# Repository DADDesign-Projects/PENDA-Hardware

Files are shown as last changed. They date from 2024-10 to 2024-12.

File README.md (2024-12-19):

# PENDA: Platform for Effects oN DAisy

Welcome to the PENDA project! This repository contains the schematics and PCB layouts created with KiCad 8.0 for a versatile digital effects platform that utilizes the **Daisy-Seed** board from **ElectroSmith**.

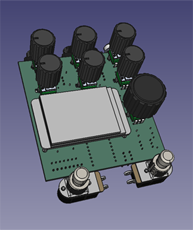
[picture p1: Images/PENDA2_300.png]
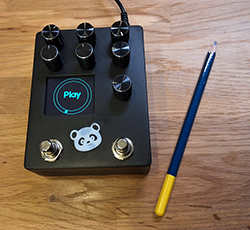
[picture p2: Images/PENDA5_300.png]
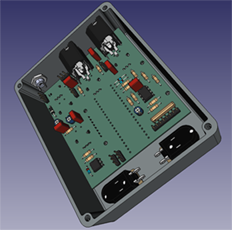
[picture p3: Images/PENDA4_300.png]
  

## Author

DAD Design

## Overview / Features

PENDA is designed to provide a range of audio effects through a user-friendly interface. The platform includes:

- **Mono Input and Output**: Simplified connectivity for easy integration into your audio setup.
- **Momentary Footswitches**: Two footswitches for hands-free operation of effects.
- **2-inch SPI Display**: Featuring the ST7789 from Waveshare, providing a clear and compact user interface (other display options are available).
- **MIDI Input**: Allows for easy integration with MIDI controllers and other devices.
- **Control Options**:
  - **4 Encoders with Pushbutton**: For easy parameter adjustment and selection.
  - **3 Analog Potentiometers**: To control input levels and the Dry/Wet mix.
- **Fully Analog Dry Circuit**: Ensures a high-quality dry signal path, maintaining the integrity of your original sound.

## Content

The **Fab** directory contains all the necessary files for fabrication.
The **PENDA** directory contains the source files for KiCad 8.0.

## Contributing

We welcome contributions to the PENDA project! If you have suggestions or improvements, please open an issue or submit a pull request.

## License

This project is licensed under the MIT License.

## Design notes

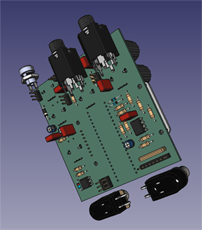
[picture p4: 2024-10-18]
Images/PENDA3_300.png

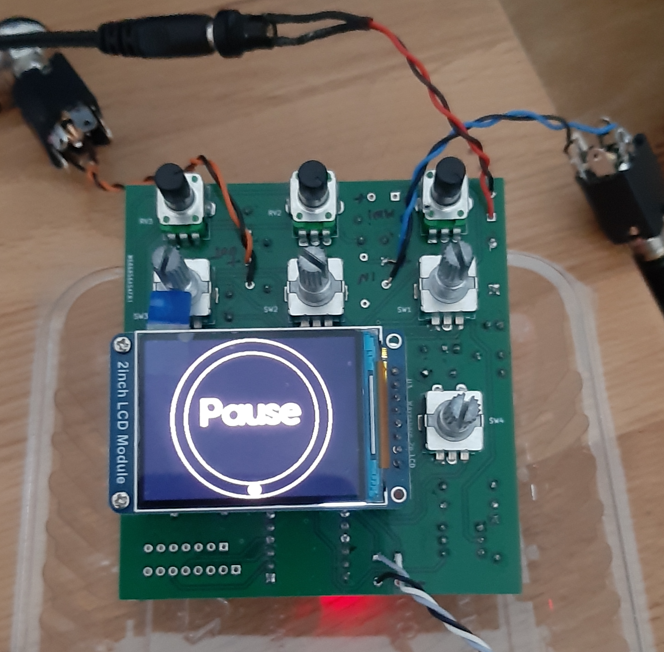
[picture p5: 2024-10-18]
Images/PENDA V1.0.png

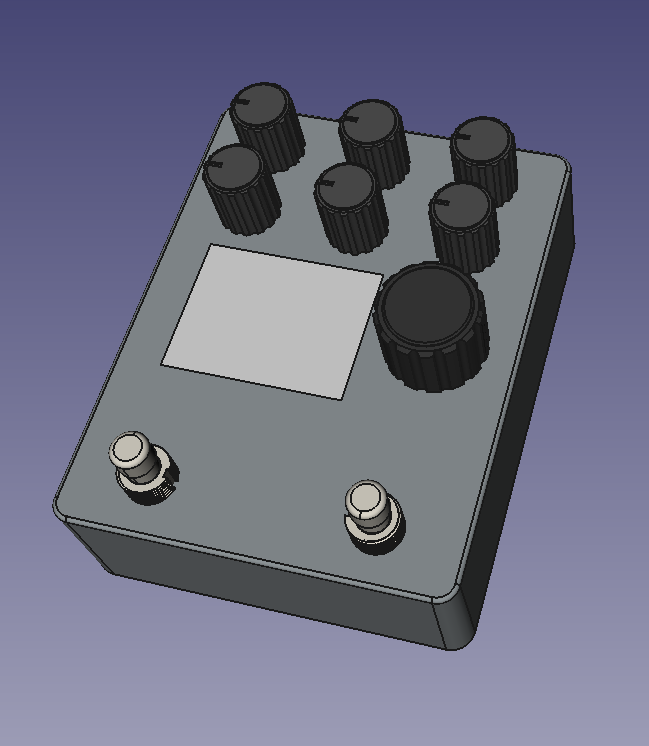
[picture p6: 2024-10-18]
Images/PENDA1.png

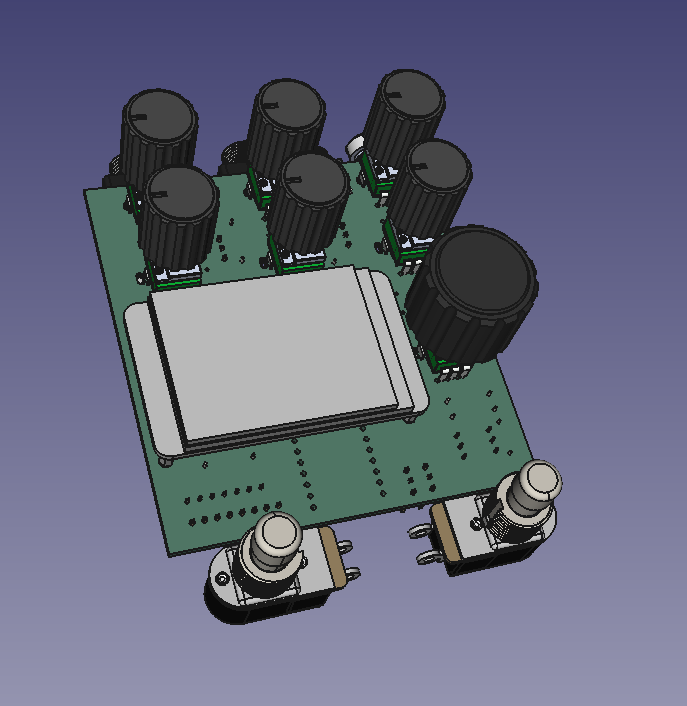
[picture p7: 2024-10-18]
Images/PENDA2.png

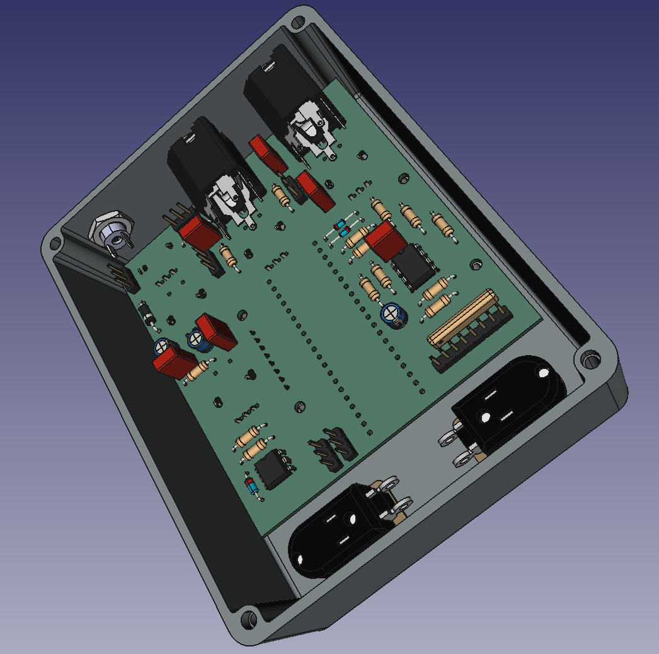
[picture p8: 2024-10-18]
Images/PENDA4.png

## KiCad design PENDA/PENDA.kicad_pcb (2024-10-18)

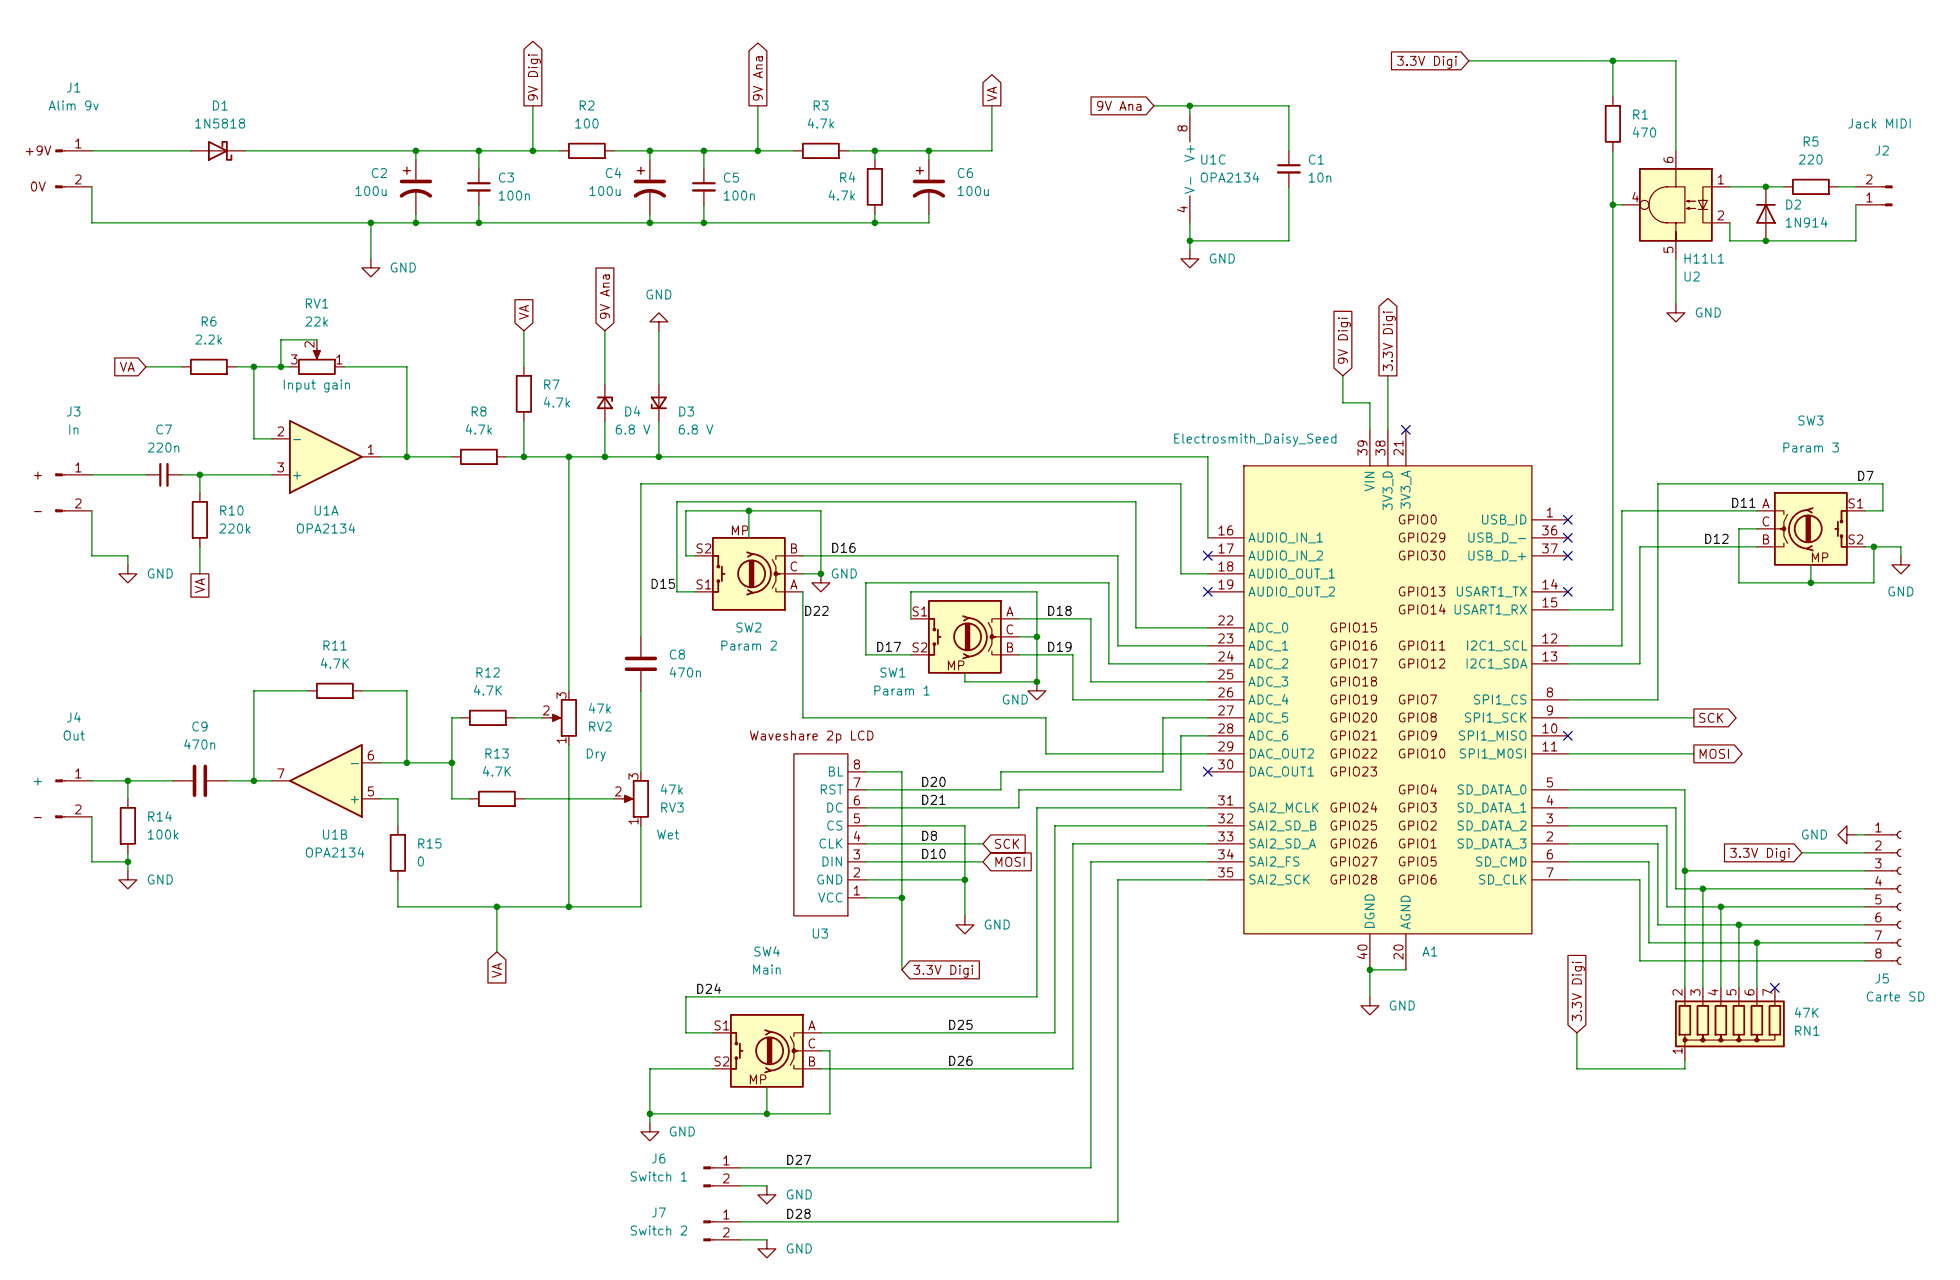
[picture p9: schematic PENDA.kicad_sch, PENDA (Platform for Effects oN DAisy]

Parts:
A1: Electrosmith_Daisy_Seed
C1: 10n; C_Rect_L7.0mm_W3.5mm_P5.00mm
C2, C4, C6: 100u; CP_Radial_D5.0mm_P2.50mm
C3, C5: 100n; C_Rect_L7.0mm_W3.5mm_P5.00mm
C7: 220n; C_Rect_L7.0mm_W3.5mm_P5.00mm
C8, C9: 470n; C_Rect_L7.0mm_W3.5mm_P5.00mm
D1: 1N5818; D_DO-41_SOD81_P10.16mm_Horizontal
D2: 1N914; D_DO-35_SOD27_P7.62mm_Horizontal
D3, D4: 6.8 V; D_DO-34_SOD68_P10.16mm_Horizontal
J1: Alim 9v; PinHeader_1x02_P5.08mm_Vertical
J2: Jack MIDI; PinHeader_1x02_P5.08mm_Vertical
J3: In; PinHeader_1x02_P5.08mm_Vertical
J4: Out; PinHeader_1x02_P5.08mm_Vertical
J5: Carte SD; PinHeader_1x08_P2.54mm_Vertical
J6: Switch 1; PinHeader_1x02_P5.08mm_Vertical
J7: Switch 2; PinHeader_1x02_P5.08mm_Vertical
R1: 470; R_Axial_DIN0207_L6.3mm_D2.5mm_P10.16mm_Horizontal
R2: 100; R_Axial_DIN0207_L6.3mm_D2.5mm_P10.16mm_Horizontal
R3, R4, R7, R8: 4.7k; R_Axial_DIN0207_L6.3mm_D2.5mm_P10.16mm_Horizontal
R5: 220; R_Axial_DIN0207_L6.3mm_D2.5mm_P10.16mm_Horizontal
R6: 2.2k; R_Axial_DIN0207_L6.3mm_D2.5mm_P10.16mm_Horizontal
R10: 220k; R_Axial_DIN0207_L6.3mm_D2.5mm_P10.16mm_Horizontal
R11, R12, R13: 4.7K; R_Axial_DIN0207_L6.3mm_D2.5mm_P10.16mm_Horizontal
R14: 100k; R_Axial_DIN0207_L6.3mm_D2.5mm_P10.16mm_Horizontal
R15: 0; R_Axial_DIN0207_L6.3mm_D2.5mm_P10.16mm_Horizontal
RN1: 47K; R_Array_SIP7
RV1: 22k; Potentiometer_Alpha_RD901F-40-00D_Single_Vertical_Center
RV2, RV3: 47k; Potentiometer_Alpha_RD901F-40-00D_Single_Vertical_Center
SW1: Param 1; RotaryEncoder_Alps_EC11E-Switch_Vertical_H20mm_Center
SW2: Param 2; RotaryEncoder_Alps_EC11E-Switch_Vertical_H20mm_Center
SW3: Param 3; RotaryEncoder_Alps_EC11E-Switch_Vertical_H20mm_Center
SW4: Main; RotaryEncoder_Alps_EC11E-Switch_Vertical_H20mm_Center
U1: OPA2134; DIP-8_W7.62mm
U2: H11L1; DIP-6_W7.62mm
U3: Waveshare 2 p LCD V2

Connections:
3.3V Digi: A1.38 (3V3_D), J5.2, R1.2, RN1.1 (common), U2.6, U3.1 (VCC), U3.8 (BL)
9V Ana: C1.1, C4.1, C5.1, D4.1 (K), R2.2, R3.1, U1.8 (V+)
9V Digi: A1.39 (VIN), C2.1, C3.1, D1.1 (K), R2.1
/D7: A1.8 (SPI1_CS), SW3.S1
/D11: A1.12 (I2C1_SCL), SW3.A
/D12: A1.13 (I2C1_SDA), SW3.B
/D15: A1.22 (ADC_0), SW2.S1
/D16: A1.23 (ADC_1), SW2.B
/D17: A1.24 (ADC_2), SW1.S2
/D18: A1.25 (ADC_3), SW1.A
/D19: A1.26 (ADC_4), SW1.B
/D20: A1.27 (ADC_5), U3.7 (RST)
/D21: A1.28 (ADC_6), U3.6 (DC)
/D22: A1.29 (DAC_OUT2), SW2.A
/D24: A1.31 (SAI2_MCLK), SW4.S1
/D25: A1.32 (SAI2_SD_B), SW4.A
/D26: A1.33 (SAI2_SD_A), SW4.B
/D27: A1.34 (SAI2_FS), J6.1
/D28: A1.35 (SAI2_SCK), J7.1
GND: A1.20 (AGND), A1.40 (DGND), C1.2, C2.2, C3.2, C4.2, C5.2, C6.2, D3.2 (A), J1.2, J3.2 (-), J4.2, J5.1, J6.2, J7.2, R4.1, R14.2, SW1.C, SW1.MP, SW1.S1, SW2.C, SW2.MP, SW2.S2, SW3.C, SW3.MP, SW3.S2, SW4.C, SW4.MP, SW4.S2, U1.4 (V-), U2.5, U3.2 (GND), U3.5 (CS); also elsewhere on the board
MOSI: A1.11 (SPI1_M0SI), U3.3 (DIN)
unnamed: A1.16 (AUDIO_IN_1), D3.1 (K), D4.2 (A), R7.1, R8.2, RV2.3
unnamed: A1.18 (AUDIO_OUT_1), C8.1
unnamed: A1.7 (SD_CLK), J5.8
unnamed: A1.6 (SD_CMD), J5.7, RN1.6 (R5)
unnamed: A1.5 (SD_DATA_0), J5.3, RN1.2 (R1)
unnamed: A1.4 (SD_DATA_1), J5.4, RN1.3 (R2)
unnamed: A1.3 (SD_DATA_2), J5.5, RN1.4 (R3)
unnamed: A1.2 (SD_DATA_3), J5.6, RN1.5 (R4)
unnamed: A1.15 (USART1_RX), R1.1, U2.4
unnamed: C8.2, RV3.3
unnamed: C9.1, R11.1, U1.7
unnamed: D1.2 (A), J1.1
unnamed: D2.2 (A), J2.1, U2.2
unnamed: D2.1 (K), R5.1, U2.1
unnamed: J2.2, R5.2
unnamed 36: C7.1, J3.1 (+); also elsewhere on the board
unnamed: C9.2, J4.1, R14.1
unnamed: R8.1, RV1.1, U1.1
unnamed: R12.2, RV2.2
unnamed: R13.2, RV3.2
unnamed: C7.2, R10.1, U1.3 (+)
unnamed: R6.2, RV1.2, RV1.3, U1.2 (-)
unnamed: R15.2, U1.5 (+)
unnamed: R11.2, R12.1, R13.1, U1.6 (-)
SCK: A1.9 (SPI1_SCK), U3.4 (CLK)
VA: C6.1, R3.2, R4.2, R6.1, R7.2, R10.2, R15.1, RV2.1, RV3.1

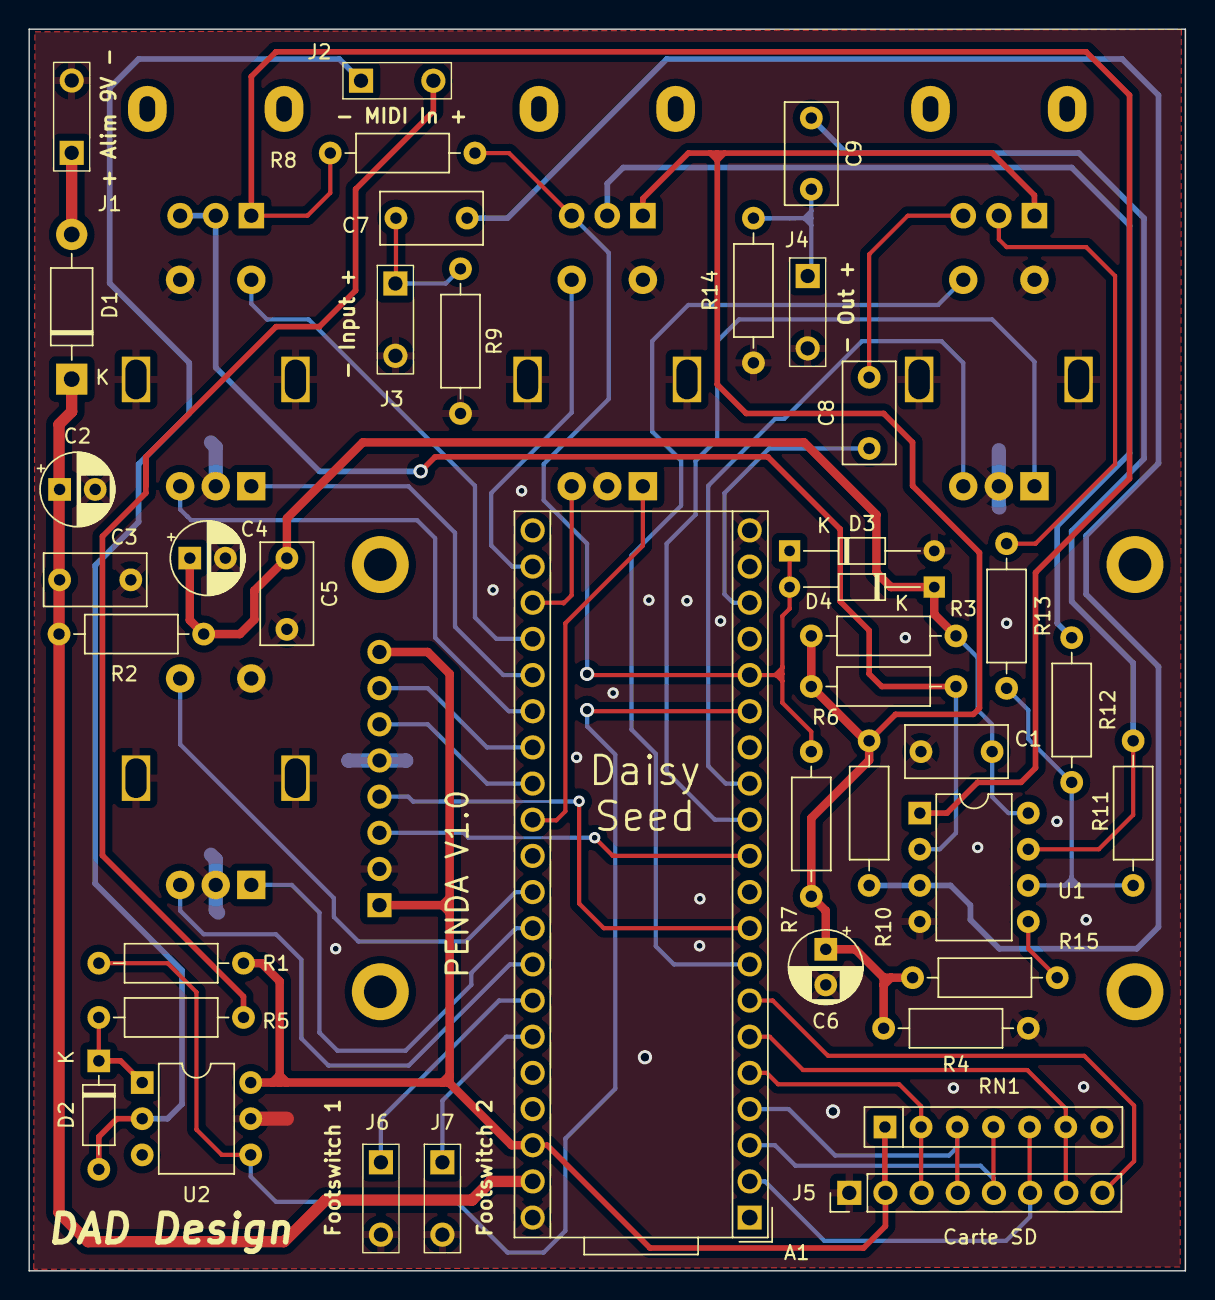
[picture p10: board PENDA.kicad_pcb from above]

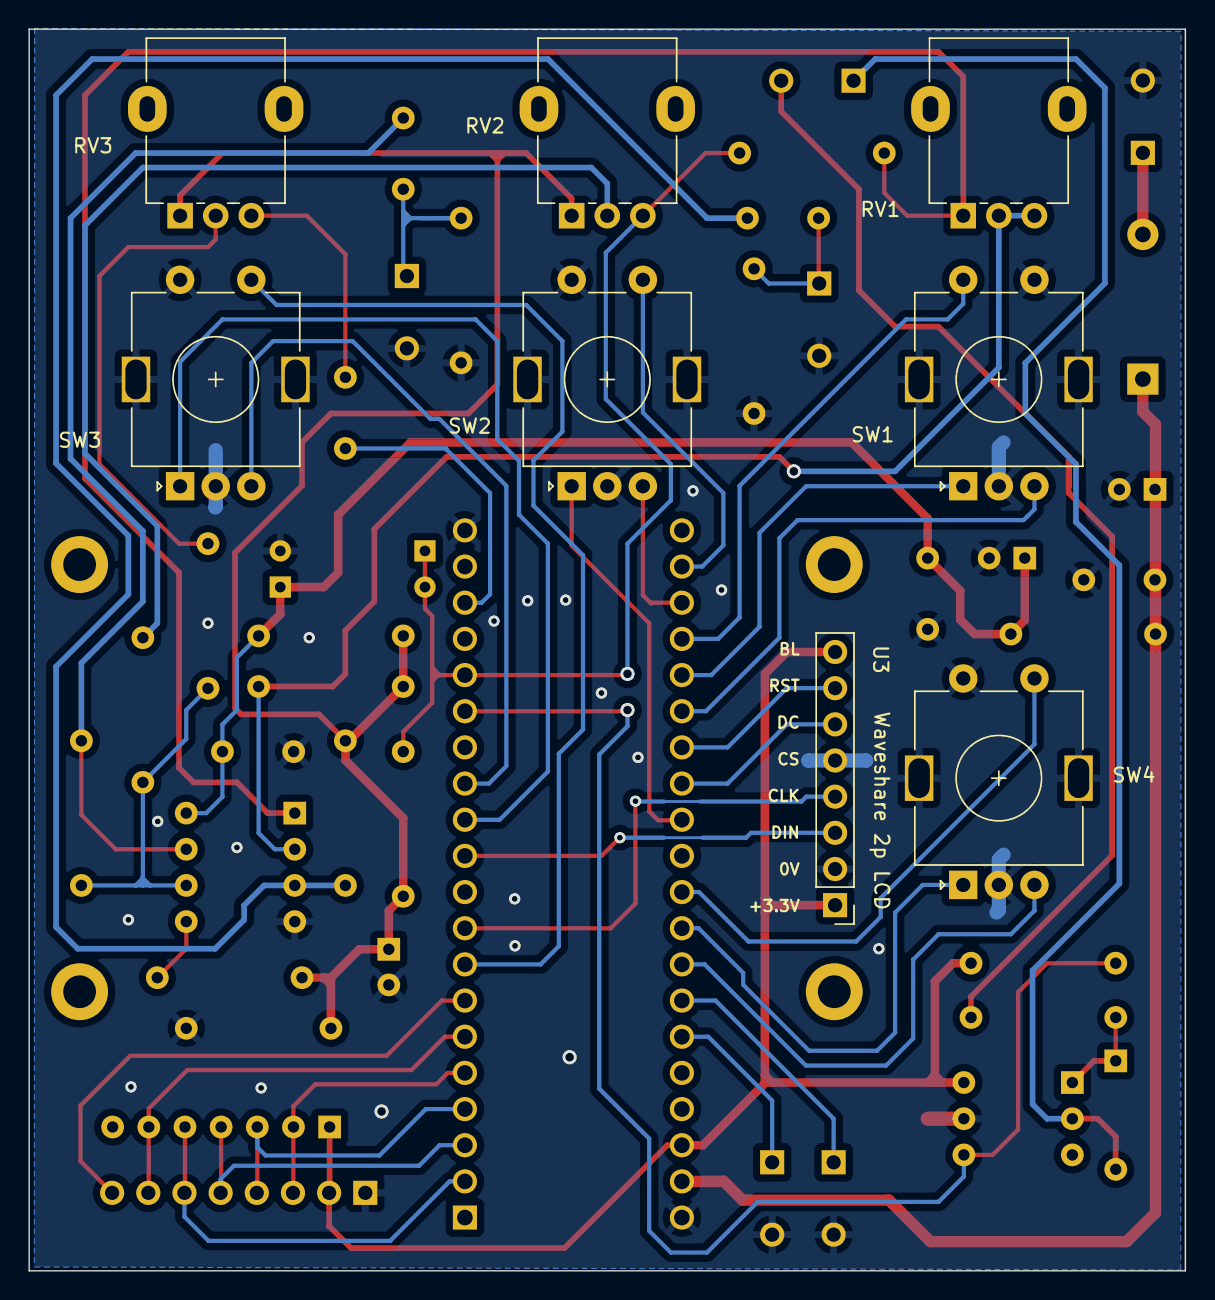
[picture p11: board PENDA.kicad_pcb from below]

Board: 2 copper layers, 81.2 x 87.2 mm, 47 parts (8 on the bottom side), 47 nets.

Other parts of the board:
R9: 1M; R_Axial_DIN0207_L6.3mm_D2.5mm_P10.16mm_Horizontal

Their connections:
GND: R9.2; also elsewhere on the board
unnamed 36: R9.1; also elsewhere on the board
